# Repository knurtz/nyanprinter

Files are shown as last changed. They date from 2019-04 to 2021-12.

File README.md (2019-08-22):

# NyanPrinter
This printer runs on STM32F103 and it prints AND plays the nyan cat!

## Idea

Thermal printers make a lot of noise while printing -- everyone, who has bought something from a shop with one of those old cash registers knows that! At the heart of such a printer lies of course a stepper motor. Making music with stepper motors is an old thing in the Arduino community. But as far as I know, nobody has ever tried to make music AND print something at the same time -- until now!

Getting picture and sound to line up is not particulary easy, because there are certain limitations to the printing speed of a thermal printer -- and thus also for the maximum pitch we can get out of the machine. 

The datasheet recommends an approximate exposure of 1 ms per line, which responds to a 1 kHz pitch. This is, unless more than 64 pixels out of the total 384 pixels per line are printed simultanously. Here we need to do devided printing, which means multiple exposure bursts for one single line. This is where things get tricky. I need to let the printer run at a fixed speed and cannot stop at a line just because I want to print more than 64 pixels. Otherwise I would get a sudden break in my music.

This is the solution I came up with: If the printer encounters a line with more than 64 pixels, it prints the first 64 (or less) pixels, then advances the motor one step, going back one step immediately in order to print the next 64 pixels and so on. I have not yet tested, if the sudden change in direction is audible. If so, I might have to change it up a little bit and print multiple lines first, then go back over them a second time.

## Hardware

- STM32F103 Bluepill Development Board: [stm32duino.com](https://web.archive.org/web/20190524151648/https://wiki.stm32duino.com/index.php?title=Blue_Pill)
- Thermal printer MATSUSHITA EPL1801S2E from [pollin.de](https://www.pollin.de/p/thermo-druckelement-matsushita-epl1801s2e-721066)
- an awesome huge blue push button from [Amazon](https://www.amazon.de/gp/product/B07BSFMZJ2) (it lights up, too!)
- A4988 stepper motor driver board like this one from [pololu.com](https://www.pololu.com/product/1182)
- RECOM R-78E5.0-0.5 DC/DC converter from [conrad.de](https://www.conrad.de/de/recom-r-78e50-05-dcdc-wandler-print-24-vdc-5-vdc-500-ma-anzahl-ausgaenge-1-x-157954.html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)
- MAX6966 led driver from [farnell.com](https://de.farnell.com/maxim-integrated-products/max6966aee/led-treiber-mit-i-o-erweiterung/dp/2516036) for fancy led stuff
- custom milled PCB with some additional components like resistors and capacitors (Eagle files following shortly)
- custom enclosure printed with the amazing Vertigo Starlight filament from [filamentworld.de](https://www.filamentworld.de/shop/pla-filament-3d-drucker/pla-filament-1-75-mm-vertigo-starlight-075-kg/) (STL files following shortly as well)

## Software

I wanted to learn more about hardware peripherals of the STM32 family in this project. This is why I use a total of 3 timers, 2 DMA channels, one SPI and one UART peripheral. Things could have probably be done less complicated, but I would not have learned anything the easy way.

TIM2 is responsible for the motor step signal. It runs at a frequency that is determined by the current pitch of the music. The motor driver makes a step at every rising edge of the signal. Also, the printer needs to advance two steps for every line. Because of that, at every update interrupt of TIM2 (which corresponds to every step of the motor) I alternate between sending new data to the printer (triggering TIM1) and starting the exposure (triggering TIM3).

Data transfer is timed by TIM1, which triggers 64 DMA requests (64 transfers * 6 "pixels" per transfer = 384 pixels per line). The DMA sends the data to 6 parallel data lines that go into 6 shift registers inside the printer. Data alignment looks weird, this is why I wrote a small python script to convert images to a special byte array.

Finally TIM3 creates a pulse that corresponds to the needed exposure time of about 750 - 1000 us (depending on the supply voltage).

UART is needed for debugging and SPI for the led driver.

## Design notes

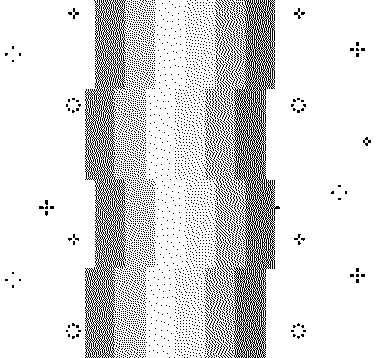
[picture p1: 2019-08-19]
Image/Source/nyan_indexed_loop.png

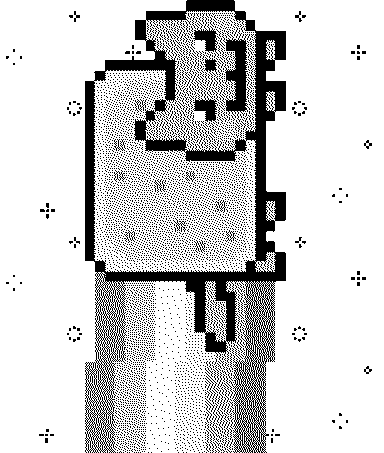
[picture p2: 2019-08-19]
Image/Source/nyan_indexed_start.png

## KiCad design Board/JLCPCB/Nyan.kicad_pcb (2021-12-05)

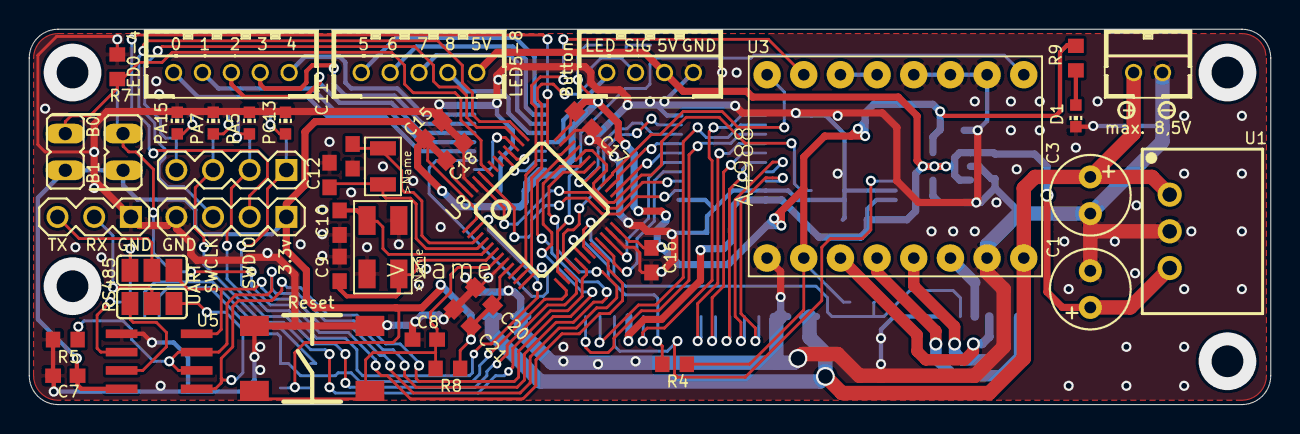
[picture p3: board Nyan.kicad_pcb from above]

Board: 2 copper layers, 86.0 x 26.0 mm, 66 parts (0 on the bottom side), 75 nets.

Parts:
C1, C3: 100u; E2,5-6
C2, C14, C21: 1u; C0603
C4, C5, C6, C7, C8, C15, C16, C17, C18, C20, C22: 100n; C0603
C9, C10: 30p; C0603
C11, C12: 15p; C0603
C13: 22n; C0603
C19: 10u; C0603
D1, D2, D3, D4, D5: CHIP-LED0603
JP1, JP2: JP1
Q1: 8M; SMD_5X3.2
Q2: 32768; SMD_3.2X1.5
R1: 300; R0603
R2: 47k; R0603
R3, R4, R5, R6, R7, R8, R9, R10, R11, R12, R13, R14: 10k; R0603
S1: 6X6_MOMENTARY_SWITCH
SJ1, SJ2: SJ_2
SV2, SV3: MA04-1_ROUND
U1: R-78C5.0-1.0; SIP3
U2: SOT23-5
U3: A4988_STEP
U4: MAX6966; QSOP-16
U5: ST3485; SO-08
U6, U7: 74HCT541PW; TSSOP20
U8: STM32F10XCXT6; TQFP48
X1: WR-WTB2.0-2_THT-VER; WR-WTB2.0-2-THT-VER
X2: WR-WTB2.0-4_THT_VER; WR-WTB2.0-4-THT-VER
X3, X4: WR-WTB2.0-5_THT-VER; WR-WTB2.0-5-THT-VER
X5: MA03-1_ROUND
X6: 68610614122
X7: 68612414422
X8: 68610414122

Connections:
+3V3: C4.1, C7.2, C14.1, C15.2, C16.2, C17.2, C18.2, C19.2, C20.2, C21.2, JP1.2, JP2.2, R1.2, R2.2, R3.2, R4.2, R8.2, R9.2, R14.1, SV2.1, U2.5, U3.VDD, U4.16, U5.8, U8.1, U8.9, U8.24, U8.36, U8.48
+5V: C1.+, C2.1, C5.2, C6.2, U1.3, U2.1, U2.3, U6.20, U7.20, X2.2, X4.1, X7.14
+12V: C3.+, U1.1, U3.VMOT, X1.2, X7.1, X7.2, X7.23, X7.24
A/TX: SJ1.2, X5.3
B/RX: SJ2.2, X5.2
BOOT0: JP1.1, R7.2, U8.44
BOOT1: JP2.1, R6.2, U8.20
BUT_LED: U4.13, X2.4
BUT_SIG: C22.1, R14.2, U8.11, X2.3
D1: U6.2, U8.45
D1_5V: U6.18, X7.5
D2: U6.3, U8.46
D2_5V: U6.17, X7.6
D3: U6.4, U8.21
D3_5V: U6.16, X7.7
D4: U6.5, U8.22
D4_5V: U6.15, X7.8
D5: U6.6, U8.25
D5_5V: U6.14, X7.9
D6: U6.7, U8.26
D6_5V: U6.13, X7.17
DCLK: U6.8, U8.29
DCLK_5V: U6.12, X7.16
FREE_LED: U4.12, X4.2
GND: C1.-, C2.2, C3.-, C4.2, C5.1, C6.1, C7.1, C8.1, C9.2, C10.2, C11.2, C12.2, C13.2, C14.2, C15.1, C16.1, C17.1, C18.1, C19.1, C20.1, C21.1, C22.2, D1.C, D2.C, D3.C, D4.C, D5.C, Q1.2, Q1.4, R5.1, R6.1, R7.1, S1.3, S1.4, SV2.4, U1.2, U2.2, U3.GND, U3.GND2, U3.MS1, U3.MS2, U3.MS3, U4.8, U5.5, U6.1, U6.10, U6.19, U7.1, U7.10, U7.19, U8.8, U8.23, U8.35, U8.47, X1.1, X2.1, X5.1, X6.6, X7.3, X7.4, X7.21, X7.22, X8.2
HEAD_THERM: R4.1, U8.18, X7.12
LATCH: U7.2, U8.28, U8.32
LATCH_5V: U7.18, X7.15
LED1: U4.3, X3.5
LED2: U4.4, X3.4
LED3: U4.5, X3.3
LED4: U4.6, X3.2
LED5: U4.7, X3.1
LED6: U4.9, X4.5
LED7: U4.10, X4.4
LED8: U4.11, X4.3
LED_CLK: U4.1, U8.39
LED_CS: U4.2, U8.12
LED_MISO: U4.14, U8.40
LED_MOSI: U4.15, U8.41
M1A: U3.1A, X6.1
M1B: U3.1B, X6.3
M2A: U3.2A, X6.2
M2B: U3.2B, X6.4
MOT_DIR: U3.DIR, U8.27
MOT_EN: U3./EN, U8.14
MOT_STP: U3.STEP, U8.10
MOT_THERM: R3.1, U8.19, X6.5
unnamed: R1.1, X8.4
unnamed: U3./RST, U3./SLP
unnamed: C8.2, R8.1, S1.1, S1.2, U8.7
unnamed: C12.1, Q2.1, U8.4
unnamed: C11.1, Q2.2, U8.3
unnamed: C10.1, Q1.3, U8.5
unnamed: C9.1, Q1.1, U8.6
unnamed: D4.A, R12.1
unnamed: D1.A, R9.1
unnamed: D2.A, R10.1
unnamed: D3.A, R11.1
unnamed: C13.1, U2.4
unnamed: D5.A, R13.1
PA5: R11.2, SV3.2, U8.15
PA7: R12.2, SV3.3, U8.17
PA15: R13.2, SV3.4, U8.38
PC13: R10.2, SV3.1, U8.2
PHOTO: R2.1, U8.13, X8.3
RS485_A: SJ1.3, U5.6
RS485_B: SJ2.1, U5.7
RTS: R5.2, U5.2, U5.3, U8.33
RX: SJ2.3, U5.1, U8.31
STROBE: U6.9, U8.16
STROBE_5V: U6.11, X7.13
SWCLK: SV2.3, U8.37
SWDIO: SV2.2, U8.34
TX: SJ1.1, U5.4, U8.30

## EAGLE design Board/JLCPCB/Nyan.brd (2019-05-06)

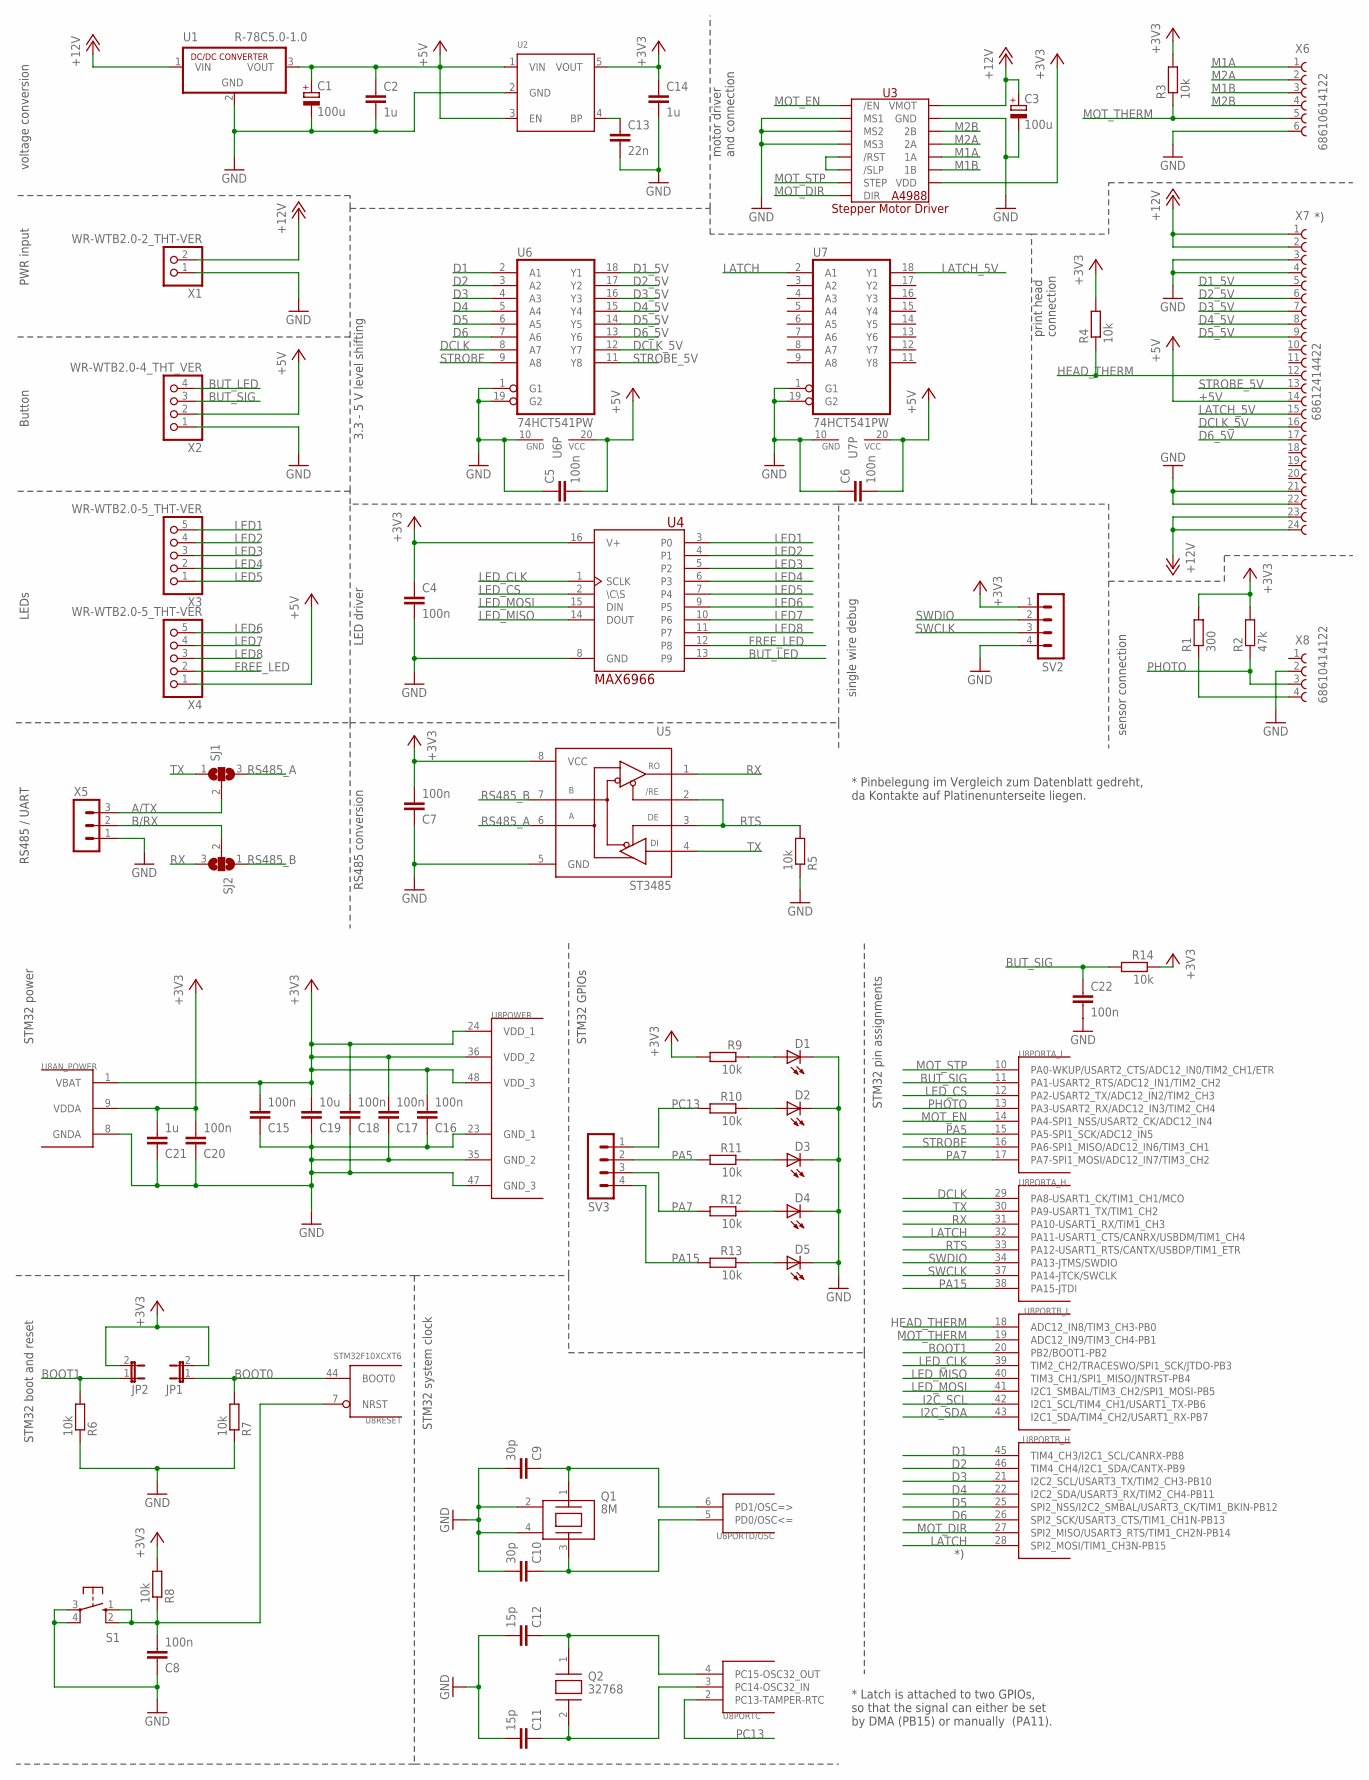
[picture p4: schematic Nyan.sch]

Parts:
C1, C3: 100u; E2,5-6
C2, C14, C21: 1u; C0603
C4, C5, C6, C7, C8, C15, C16, C17, C18, C20, C22: 100n; C0603
C9, C10: 30p; C0603
C11, C12: 15p; C0603
C13: 22n; C0603
C19: 10u; C0603
D1, D2, D3, D4, D5: LEDCHIP-LED0603; CHIP-LED0603
JP1, JP2: JP1E; JP1
Q1: 8M; SMD_5X3.2
Q2: 32768; SMD_3.2X1.5
R1: 300; R0603
R2: 47k; R0603
R3, R4, R5, R6, R7, R8, R9, R10, R11, R12, R13, R14: 10k; R0603
S1: 6X6_MOMENTARY_SWITCH
SJ1, SJ2: SJ2W; SJ_2
SV2, SV3: MA04-1ROUND_PAD; MA04-1_ROUND
U1: R-78C5.0-1.0; SIP3
U2: RT9193; SOT23-5
U3: A4988_STEP
U4: MAX6966; QSOP-16
U5: ST3485; SO-08
U6, U7: 74HCT541PW; TSSOP20
U8: STM32F10XCXT6; TQFP48
X1: WR-WTB2.0-2_THT-VER; WR-WTB2.0-2-THT-VER
X2: WR-WTB2.0-4_THT_VER; WR-WTB2.0-4-THT-VER
X3, X4: WR-WTB2.0-5_THT-VER; WR-WTB2.0-5-THT-VER
X5: MA03-1ROUND_PAD; MA03-1_ROUND
X6: 68610614122
X7: 68612414422
X8: 68610414122

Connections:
+3V3: C4.1, C7.2, C14.1, C15.2, C16.2, C17.2, C18.2, C19.2, C20.2, C21.2, JP1.2, JP2.2, R1.2, R2.2, R3.2, R4.2, R8.2, R9.2, R14.1, SV2.1, U2.5 (VOUT), U3.VDD, U4.16 (V+), U5.8 (VCC), U8.1 (VBAT), U8.9 (VDDA), U8.24 (VDD_1), U8.36 (VDD_2), U8.48 (VDD_3)
+5V: C1.+, C2.1, C5.2, C6.2, U1.3 (VOUT), U2.1 (VIN), U2.3 (EN), U6.20 (VCC), U7.20 (VCC), X2.2, X4.1, X7.14
+12V: C3.+, U1.1 (VIN), U3.VMOT, X1.2, X7.1, X7.2, X7.23, X7.24
A/TX: SJ1.2, X5.3
B/RX: SJ2.2, X5.2
BOOT0: JP1.1, R7.2, U8.44 (BOOT0)
BOOT1: JP2.1, R6.2, U8.20 (PB2/BOOT1-PB2)
BUT_LED: U4.13 (P9), X2.4
BUT_SIG: C22.1, R14.2, U8.11 (PA1-USART2_RTS/ADC12_IN1/TIM2_CH2), X2.3
D1: U6.2 (A1), U8.45 (TIM4_CH3/I2C1_SCL/CANRX-PB8)
D1_5V: U6.18 (Y1), X7.5
D2: U6.3 (A2), U8.46 (TIM4_CH4/I2C1_SDA/CANTX-PB9)
D2_5V: U6.17 (Y2), X7.6
D3: U6.4 (A3), U8.21 (I2C2_SCL/USART3_TX/TIM2_CH3-PB10)
D3_5V: U6.16 (Y3), X7.7
D4: U6.5 (A4), U8.22 (I2C2_SDA/USART3_RX/TIM2_CH4-PB11)
D4_5V: U6.15 (Y4), X7.8
D5: U6.6 (A5), U8.25 (SPI2_NSS/I2C2_SMBAL/USART3_CK/TIM1_BKIN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)
D5_5V: U6.14 (Y5), X7.9
D6: U6.7 (A6), U8.26 (SPI2_SCK/USART3_CTS/TIM1_CH1N-PB13)
D6_5V: U6.13 (Y6), X7.17
DCLK: U6.8 (A7), U8.29 (PA8-USART1_CK/TIM1_CH1/MCO)
DCLK_5V: U6.12 (Y7), X7.16
FREE_LED: U4.12 (P8), X4.2
GND: C1.-, C2.2, C3.-, C4.2, C5.1, C6.1, C7.1, C8.1, C9.2, C10.2, C11.2, C12.2, C13.2, C14.2, C15.1, C16.1, C17.1, C18.1, C19.1, C20.1, C21.1, C22.2, D1.C, D2.C, D3.C, D4.C, D5.C, Q1.2, Q1.4, R5.1, R6.1, R7.1, S1.3, S1.4, SV2.4, U1.2 (GND), U2.2 (GND), U3.GND, U3.GND2 (GND), U3.MS1, U3.MS2, U3.MS3, U4.8 (GND), U5.5 (GND), U6.1 (G1), U6.10 (GND), U6.19 (G2), U7.1 (G1), U7.10 (GND), U7.19 (G2), U8.8 (GNDA), U8.23 (GND_1), U8.35 (GND_2), U8.47 (GND_3), X1.1, X2.1, X5.1, X6.6, X7.3, X7.4, X7.21, X7.22, X8.2
HEAD_THERM: R4.1, U8.18 (ADC12_IN8/TIM3_CH3-PB0), X7.12
I2C_SCL: U8.42 (I2C1_SCL/TIM4_CH1/USART1_TX-PB6)
I2C_SDA: U8.43 (I2C1_SDA/TIM4_CH2/USART1_RX-PB7)
LATCH: U7.2 (A1), U8.28 (SPI2_MOSI/TIM1_CH3N-PB15), U8.32 (PA11-USART1_CTS/CANRX/USBDM/TIM1_CH4)
LATCH_5V: U7.18 (Y1), X7.15
LED1: U4.3 (P0), X3.5
LED2: U4.4 (P1), X3.4
LED3: U4.5 (P2), X3.3
LED4: U4.6 (P3), X3.2
LED5: U4.7 (P4), X3.1
LED6: U4.9 (P5), X4.5
LED7: U4.10 (P6), X4.4
LED8: U4.11 (P7), X4.3
LED_CLK: U4.1 (SCLK), U8.39 (TIM2_CH2/TRACESWO/SPI1_SCK/JTDO-PB3)
LED_CS: U4.2 (\C\S), U8.12 (PA2-USART2_TX/ADC12_IN2/TIM2_CH3)
LED_MISO: U4.14 (DOUT), U8.40 (TIM3_CH1/SPI1_MISO/JNTRST-PB4)
LED_MOSI: U4.15 (DIN), U8.41 (I2C1_SMBAL/TIM3_CH2/SPI1_MOSI-PB5)
M1A: U3.1A, X6.1
M1B: U3.1B, X6.3
M2A: U3.2A, X6.2
M2B: U3.2B, X6.4
MOT_DIR: U3.DIR, U8.27 (SPI2_MISO/USART3_RTS/TIM1_CH2N-PB14)
MOT_EN: U3./EN, U8.14 (PA4-SPI1_NSS/USART2_CK/ADC12_IN4)
MOT_STP: U3.STEP, U8.10 (PA0-WKUP/USART2_CTS/ADC12_IN0/TIM2_CH1/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)
MOT_THERM: R3.1, U8.19 (ADC12_IN9/TIM3_CH4-PB1), X6.5
unnamed: R1.1, X8.4
unnamed: U3./RST, U3./SLP
unnamed: C8.2, R8.1, S1.1, S1.2, U8.7 (NRST)
unnamed: C12.1, Q2.1, U8.4 (PC15-OSC32_OUT)
unnamed: C11.1, Q2.2, U8.3 (PC14-OSC32_IN)
unnamed: C10.1, Q1.3, U8.5 (PD0/OSC<=)
unnamed: C9.1, Q1.1, U8.6 (PD1/OSC=>)
unnamed: D4.A, R12.1
unnamed: D1.A, R9.1
unnamed: D2.A, R10.1
unnamed: D3.A, R11.1
unnamed: C13.1, U2.4 (BP)
unnamed: D5.A, R13.1
PA5: R11.2, SV3.2, U8.15 (PA5-SPI1_SCK/ADC12_IN5)
PA7: R12.2, SV3.3, U8.17 (PA7-SPI1_MOSI/ADC12_IN7/TIM3_CH2)
PA15: R13.2, SV3.4, U8.38 (PA15-JTDI)
PC13: R10.2, SV3.1, U8.2 (PC13-TAMPER-RTC)
PHOTO: R2.1, U8.13 (PA3-USART2_RX/ADC12_IN3/TIM2_CH4), X8.3
RS485_A: SJ1.3, U5.6 (A)
RS485_B: SJ2.1, U5.7 (B)
RTS: R5.2, U5.2 (!RE), U5.3 (DE), U8.33 (PA12-USART1_RTS/CANTX/USBDP/TIM1_ETR)
RX: SJ2.3, U5.1 (RO), U8.31 (PA10-USART1_RX/TIM1_CH3)
STROBE: U6.9 (A8), U8.16 (PA6-SPI1_MISO/ADC12_IN6/TIM3_CH1)
STROBE_5V: U6.11 (Y8), X7.13
SWCLK: SV2.3, U8.37 (PA14-JTCK/SWCLK)
SWDIO: SV2.2, U8.34 (PA13-JTMS/SWDIO)
TX: SJ1.1, U5.4 (DI), U8.30 (PA9-USART1_TX/TIM1_CH2)

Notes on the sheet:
Button
PWR input
LEDs
RS485 / UART
* Latch is attached to two GPIOs, so that the signal can either be set by DMA (PB15) or manually (PA11).
* Pinbelegung im Vergleich zum Datenblatt gedreht, da Kontakte auf Platinenunterseite liegen.
voltage conversion
LED driver
RS485 conversion
3.3 - 5 V level shifting
motor driver and connection
print head connection
sensor connection
single wire debug
STM32 power
STM32 boot and reset
STM32 system clock
STM32 GPIOs
STM32 pin assignments

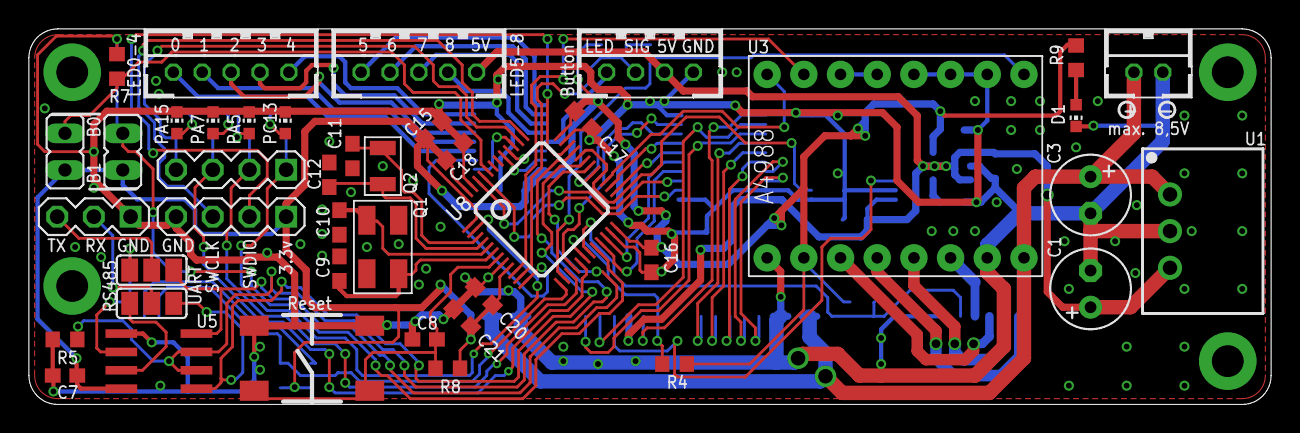
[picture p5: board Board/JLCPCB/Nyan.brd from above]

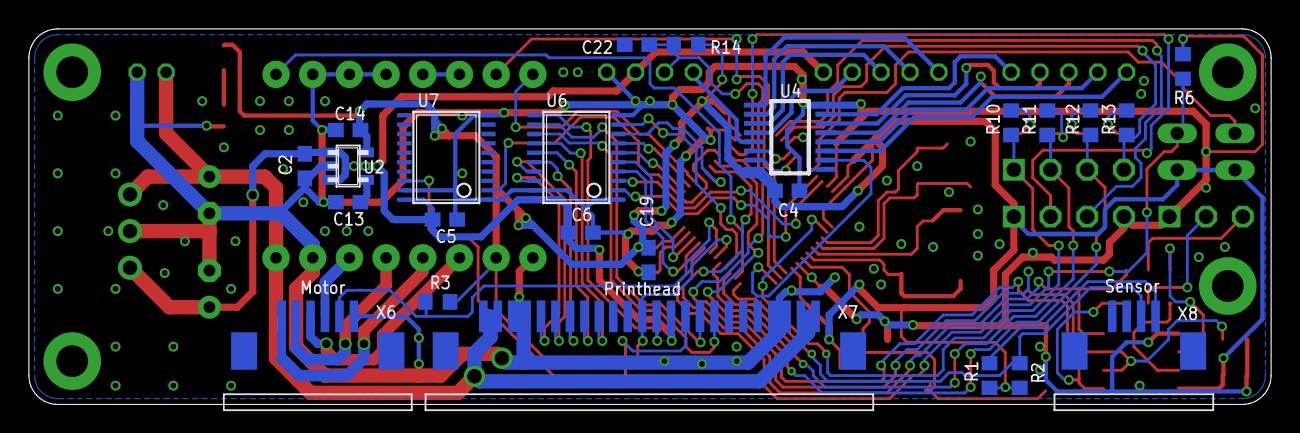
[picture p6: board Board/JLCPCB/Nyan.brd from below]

Board: 2 copper layers, 86.0 x 26.0 mm, 66 parts (24 on the bottom side), 75 nets.

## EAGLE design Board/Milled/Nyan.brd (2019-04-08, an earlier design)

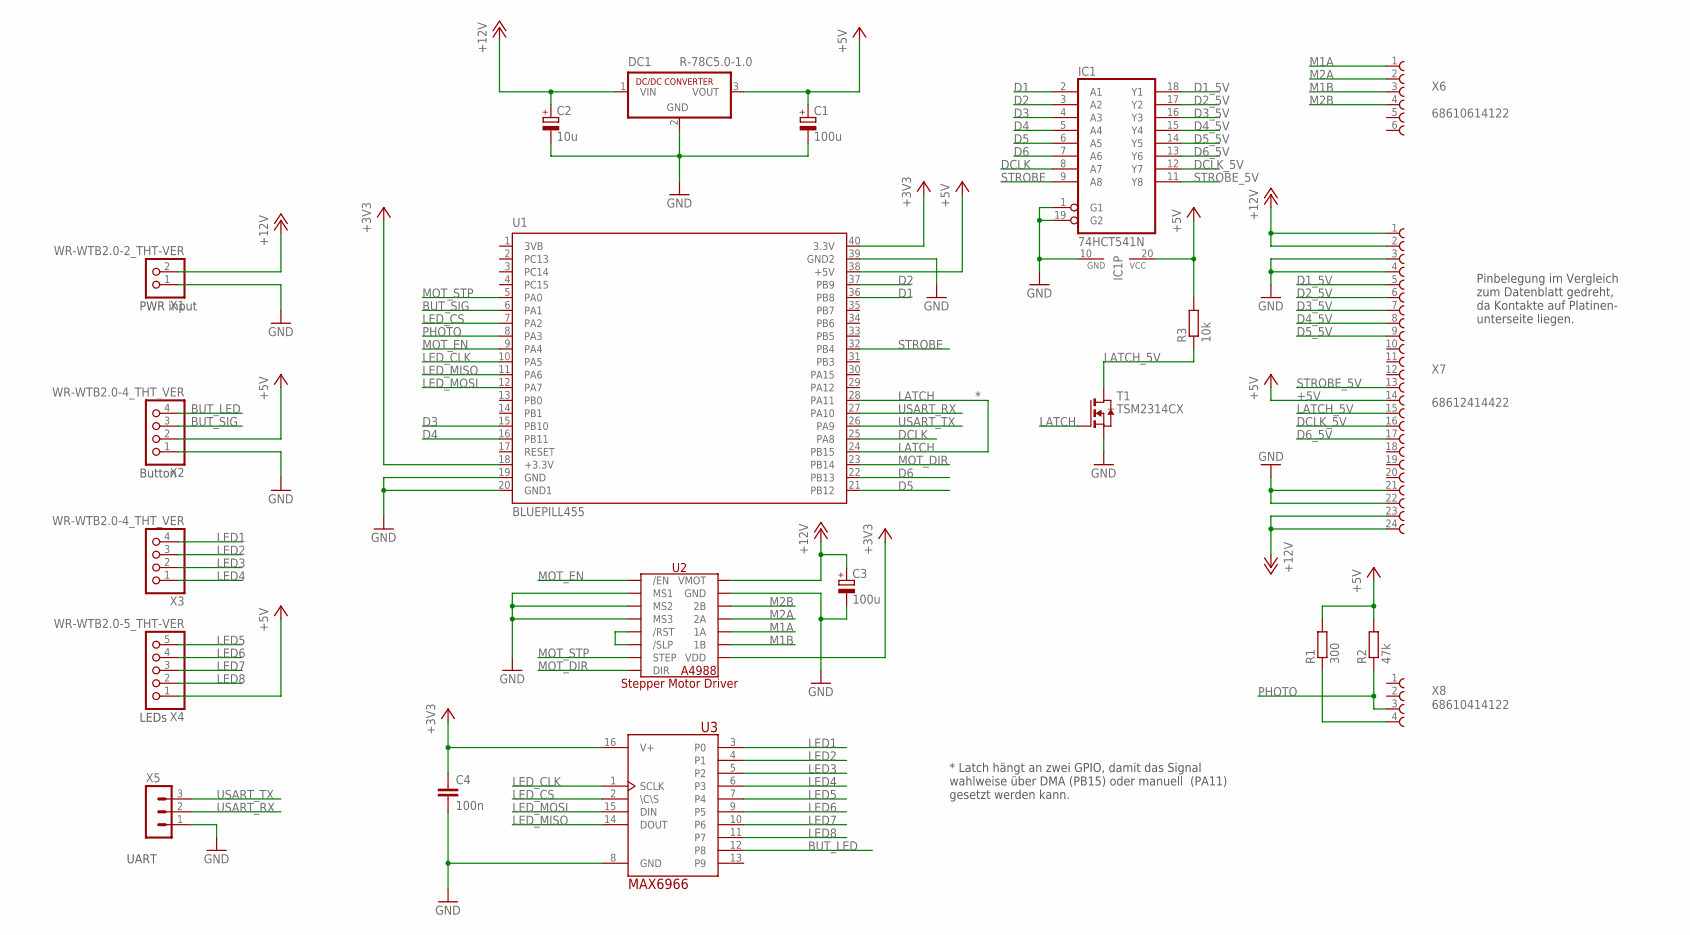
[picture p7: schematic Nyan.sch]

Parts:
C1, C3: 100u; E2,5-6
C2: 10u; E2,5-6
C4: 100n; C075-032X103
DC1: R-78C5.0-1.0; SIP3
IC1: 74HCT541N; DIL20
R1: 300; 0204/7
R2: 47k; 0204/7
R3: 10k; R0603
T1: TSM2314CX; SOT-23
U1: BLUEPILL455; DIL40
U2: A4988_STEP
U3: MAX6966; QSOP-16
X1: WR-WTB2.0-2_THT-VER; WR-WTB2.0-2-THT-VER
X2, X3: WR-WTB2.0-4_THT_VER; WR-WTB2.0-4-THT-VER
X4: WR-WTB2.0-5_THT-VER; WR-WTB2.0-5-THT-VER
X5: MA03-1ROUND_PAD; MA03-1_ROUND
X6: 68610614122
X7: 68612414422
X8: 68610414122

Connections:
+3V3: C4.1, U1.18 (+3.3V), U1.40 (3.3V), U2.VDD, U3.16 (V+)
+5V: C1.+, DC1.3 (VOUT), IC1.20 (VCC), R1.2, R2.2, R3.2, U1.38 (+5V), X2.2, X4.1, X7.14
+12V: C2.+, C3.+, DC1.1 (VIN), U2.VMOT, X1.2, X7.1, X7.2, X7.23, X7.24
BUT_LED: U3.12 (P8), X2.4
BUT_SIG: U1.6 (PA1), X2.3
D1: IC1.2 (A1), U1.36 (PB8)
D1_5V: IC1.18 (Y1), X7.5
D2: IC1.3 (A2), U1.37 (PB9)
D2_5V: IC1.17 (Y2), X7.6
D3: IC1.4 (A3), U1.15 (PB10)
D3_5V: IC1.16 (Y3), X7.7
D4: IC1.5 (A4), U1.16 (PB11)
D4_5V: IC1.15 (Y4), X7.8
D5: IC1.6 (A5), U1.21 (PB12)
D5_5V: IC1.14 (Y5), X7.9
D6: IC1.7 (A6), U1.22 (PB13)
D6_5V: IC1.13 (Y6), X7.17
DCLK: IC1.8 (A7), U1.25 (PA8)
DCLK_5V: IC1.12 (Y7), X7.16
GND: C1.-, C2.-, C3.-, C4.2, DC1.2 (GND), IC1.1 (G1), IC1.10 (GND), IC1.19 (G2), T1.2 (S), U1.19 (GND), U1.20 (GND1), U1.39 (GND2), U2.GND, U2.GND2 (GND), U2.MS1, U2.MS2, U2.MS3, U3.8 (GND), X1.1, X2.1, X5.1, X7.3, X7.4, X7.21, X7.22
LATCH: T1.1 (G), U1.24 (PB15), U1.28 (PA11)
LATCH_5V: R3.1, T1.3 (D), X7.15
LED1: U3.3 (P0), X3.4
LED2: U3.4 (P1), X3.3
LED3: U3.5 (P2), X3.2
LED4: U3.6 (P3), X3.1
LED5: U3.7 (P4), X4.5
LED6: U3.9 (P5), X4.4
LED7: U3.10 (P6), X4.3
LED8: U3.11 (P7), X4.2
LED_CLK: U1.10 (PA5), U3.1 (SCLK)
LED_CS: U1.7 (PA2), U3.2 (\C\S)
LED_MISO: U1.11 (PA6), U3.14 (DOUT)
LED_MOSI: U1.12 (PA7), U3.15 (DIN)
M1A: U2.1A, X6.1
M1B: U2.1B, X6.3
M2A: U2.2A, X6.2
M2B: U2.2B, X6.4
MOT_DIR: U1.23 (PB14), U2.DIR
MOT_EN: U1.9 (PA4), U2./EN
MOT_STP: U1.5 (PA0), U2.STEP
unnamed: R1.1, X8.4
unnamed: U2./RST, U2./SLP
PB3: U1.31 (PB3)
PHOTO: R2.1, U1.8 (PA3), X8.3
STROBE: IC1.9 (A8), U1.32 (PB4)
STROBE_5V: IC1.11 (Y8), X7.13
USART_RX: U1.27 (PA10), X5.2
USART_TX: U1.26 (PA9), X5.3

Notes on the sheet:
Button
PWR input
LEDs
UART
* Latch hängt an zwei GPIO, damit das Signal wahlweise über DMA (PB15) oder manuell (PA11) gesetzt werden kann.
Pinbelegung im Vergleich zum Datenblatt gedreht, da Kontakte auf Platinen- unterseite liegen.

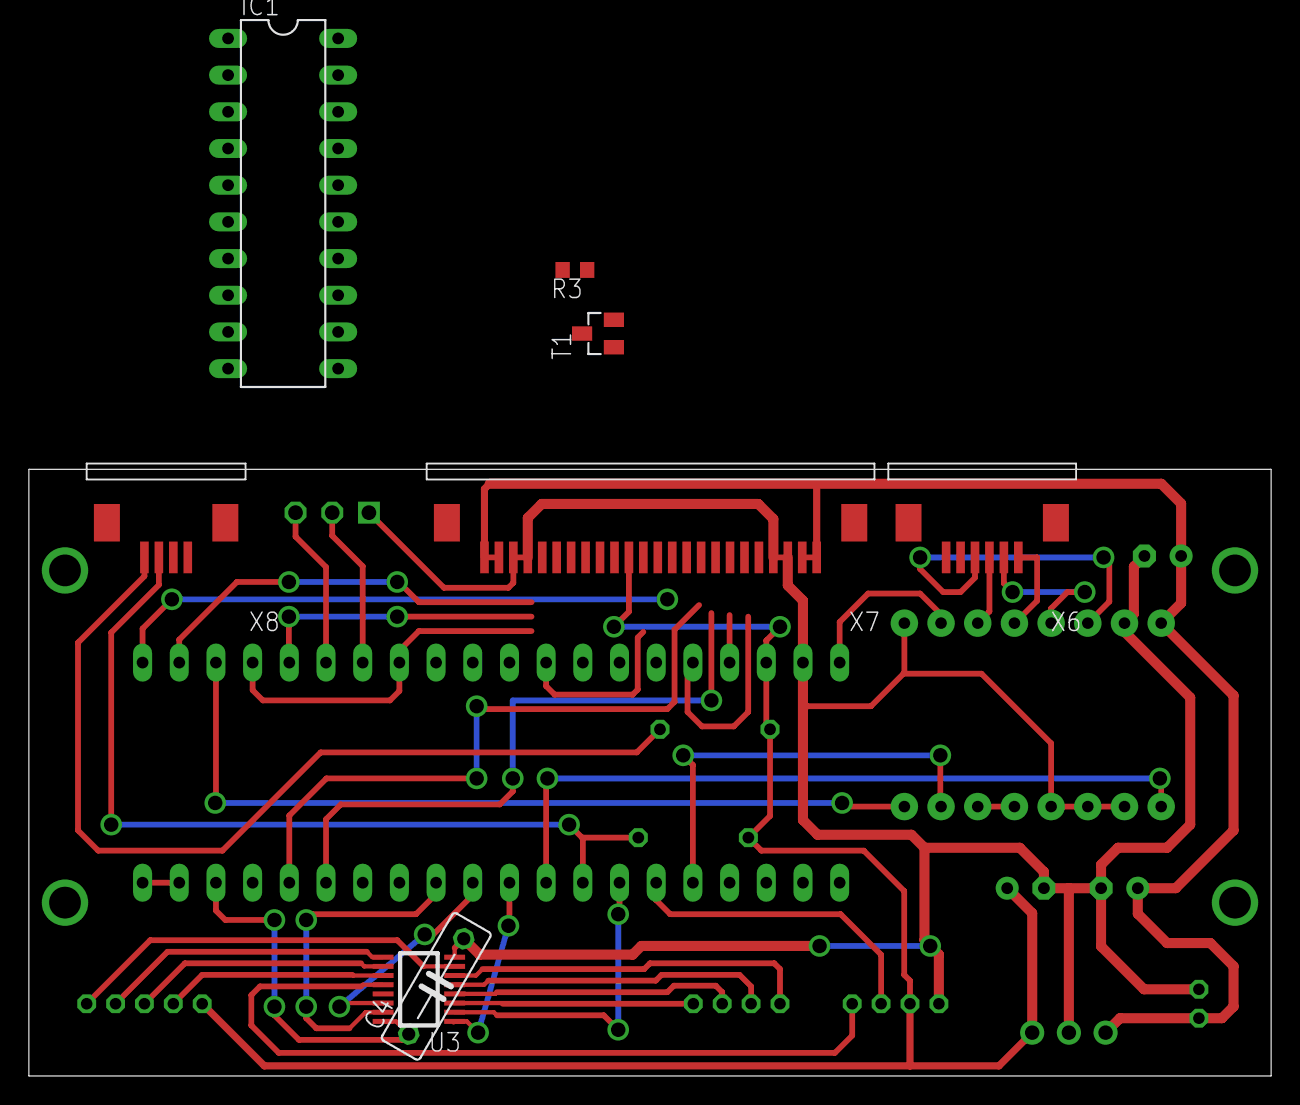
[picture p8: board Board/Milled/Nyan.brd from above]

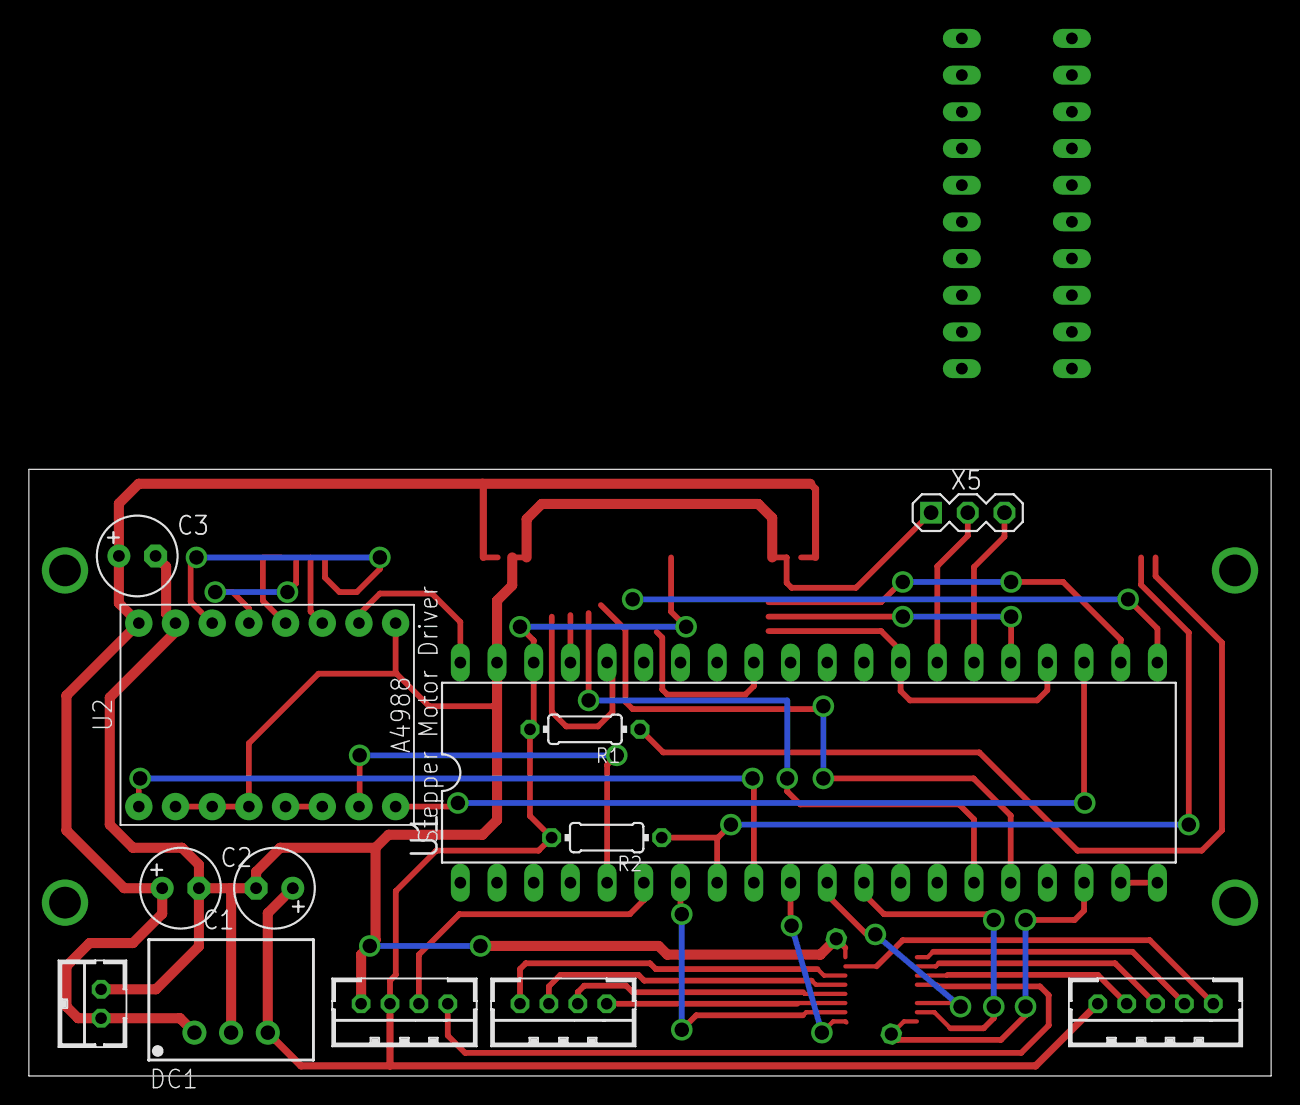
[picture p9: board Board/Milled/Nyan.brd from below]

Board: 2 copper layers, 86.0 x 42.0 mm, 21 parts (13 on the bottom side), 48 nets.

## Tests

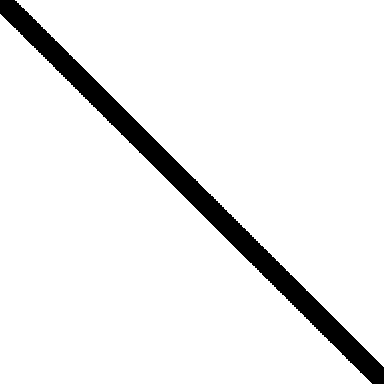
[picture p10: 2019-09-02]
Image/Source/test.png

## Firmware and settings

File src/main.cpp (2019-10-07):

/**
 * @main.cpp
 *
 * NyanPrinter main source code
 *
 * Johannes Herold, 2019
 *
 * Additional info on STM32F103
 * https://www.st.com/en/microcontrollers/stm32f103.html?querycriteria=productId=LN1565
 *
 */

#include "stm32f10x.h"
#include "stm32f10x_conf.h"

#include "delay.h"
#include "init.h"
#include "helper.h"
#include "pins.h"
#include "notes.h"

#include "image_nyan_start.h"
#include "image_nyan_loop.h"

#define FRAMERATE				25
#define FRAME_PERIOD			400
#define BREATHING_PERIOD		4

#define MUSIC_BPM				120
const int thirtysecond = (60000 / MUSIC_BPM) >> 5;		// amount of milliseconds for one thirtysecond note

int frametimer = 0;				// duration until next frame update
int musictimer = 0;				// duration until next note

uint8_t current_frame = 0;

uint8_t breathing_table[] = {
	3, 3, 3, 3, 4, 4, 5, 6, 8, 9, 11, 13, 15, 17, 20,
	23, 26, 29, 33, 37, 42, 46, 52, 57, 64, 70, 77, 84,
	92, 100, 109, 118, 127, 136, 146, 155, 165, 175, 185,
	194, 203, 212, 220, 227, 234, 240, 245, 248, 251, 253,
	254, 253, 251, 248, 245, 240, 234, 227, 220, 212, 203,
	194, 185, 175, 165, 155, 146, 136, 127, 118, 109, 100,
	92, 84, 77, 70, 64, 57, 52, 46, 42, 37, 33, 29, 26, 23,
	20, 17, 15, 13, 11, 9, 8, 6, 5, 4, 4, 3, 3, 3
};


int main(void) {

	SystemInit();


	// initialize some stuff
	delay_init(DELAY_RESOLUTION_100_US);				// configures systick and systick handler, resets uptime counter
	gpio_init();
	printer_clk_init();
	motor_step_init();
	printer_strobe_init();
	image_dma_init(image_nyan_start, image_nyan_start_length);
	led_spi_init();

	// enable motor
	GPIO_WriteBit(MOTOR_EN_PORT, MOTOR_EN_PIN, MOTOR_EN_SET_STATE);
	//set_motor_freq(NOTE_D);
	TIM_Cmd(TIM2, ENABLE);

	while(1) {

		// wait until another interval of delay resolution has passed
		while(!systick_int);
		systick_int = 0;

		// if (musictimer >= music_interval)
		// get next note / pause from song array
		// set pitch or disable motor for a pause
		// calculate new value for musictimer
		// musictimer = thirtysecond << 2		// example for one sixteenth length

		if (!frametimer) {
			frametimer = FRAME_PERIOD;
			spi_led_send(4, breathing_table[current_frame++]);			// update debug led attached to P4
			if (current_frame >= (FRAMERATE * BREATHING_PERIOD)) current_frame = 0;
		}

		musictimer--;
		frametimer--;			// systick configured to 1000 Hz -> counts milliseconds

	}

	return 0;
}

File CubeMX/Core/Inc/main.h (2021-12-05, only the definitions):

#define false   0
#define true    1
#define LED1_Pin GPIO_PIN_13
#define LED1_GPIO_Port GPIOC
#define MOT_STP_Pin GPIO_PIN_0
#define MOT_STP_GPIO_Port GPIOA
#define BIG_BUTTON_Pin GPIO_PIN_1
#define BIG_BUTTON_GPIO_Port GPIOA
#define LED_CS_Pin GPIO_PIN_2
#define LED_CS_GPIO_Port GPIOA
#define PHOTO_Pin GPIO_PIN_3
#define PHOTO_GPIO_Port GPIOA
#define MOT_EN_Pin GPIO_PIN_4
#define MOT_EN_GPIO_Port GPIOA
#define LED2_Pin GPIO_PIN_5
#define LED2_GPIO_Port GPIOA
#define STROBE_Pin GPIO_PIN_6
#define STROBE_GPIO_Port GPIOA
#define LED3_Pin GPIO_PIN_7
#define LED3_GPIO_Port GPIOA
#define HEAD_NTC_Pin GPIO_PIN_0
#define HEAD_NTC_GPIO_Port GPIOB
#define MOT_NTC_Pin GPIO_PIN_1
#define MOT_NTC_GPIO_Port GPIOB
#define D3_Pin GPIO_PIN_10
#define D3_GPIO_Port GPIOB
#define D4_Pin GPIO_PIN_11
#define D4_GPIO_Port GPIOB
#define D5_Pin GPIO_PIN_12
#define D5_GPIO_Port GPIOB
#define D6_Pin GPIO_PIN_13
#define D6_GPIO_Port GPIOB
#define MOT_DIR_Pin GPIO_PIN_14
#define MOT_DIR_GPIO_Port GPIOB
#define DCLK_Pin GPIO_PIN_8
#define DCLK_GPIO_Port GPIOA
#define LATCH_Pin GPIO_PIN_11
#define LATCH_GPIO_Port GPIOA
#define LED4_Pin GPIO_PIN_15
#define LED4_GPIO_Port GPIOA
#define LED_CLK_Pin GPIO_PIN_3
#define LED_CLK_GPIO_Port GPIOB
#define LED_MISO_Pin GPIO_PIN_4
#define LED_MISO_GPIO_Port GPIOB
#define LED_MOSI_Pin GPIO_PIN_5
#define LED_MOSI_GPIO_Port GPIOB
#define D1_Pin GPIO_PIN_8
#define D1_GPIO_Port GPIOB
#define D2_Pin GPIO_PIN_9
#define D2_GPIO_Port GPIOB

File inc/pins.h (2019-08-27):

/*
 * pins.h
 *
 *  Created on: May 27, 2019
 *  Author: Johannes Herold
 */

#ifndef PINS_H_
#define PINS_H_


// ******** Onboard LED pins ***********
#define LED1_PORT                   GPIOA
#define LED1_PIN                    GPIO_Pin_15

#define LED2_PORT                   GPIOA
#define LED2_PIN                    GPIO_Pin_7

#define LED3_PORT                   GPIOA
#define LED3_PIN                    GPIO_Pin_5

#define LED4_PORT                   GPIOC
#define LED4_PIN                    GPIO_Pin_13

#define LED_SET_STATE				Bit_SET
#define LED_RESET_STATE				Bit_RESET


// ******** SPI LED driver pins ***********
#define LED_CS_PORT	 				GPIOA
#define LED_CS_PIN					GPIO_Pin_2
#define LED_CS_SET_STATE			Bit_RESET
#define LED_CS_RESET_STATE			Bit_SET

#define LED_CLOCK_PORT				GPIOB
#define LED_CLOCK_PIN				GPIO_Pin_3

#define LED_MISO_PORT				GPIOB
#define LED_MISO_PIN				GPIO_Pin_4

#define LED_MOSI_PORT				GPIOB
#define LED_MOSI_PIN				GPIO_Pin_5


// ******** MOTOR pins ***********
#define MOTOR_STEP_PORT             GPIOA
#define MOTOR_STEP_PIN              GPIO_Pin_0

#define MOTOR_EN_PORT               GPIOA
#define MOTOR_EN_PIN                GPIO_Pin_4
#define MOTOR_EN_SET_STATE			Bit_RESET
#define MOTOR_EN_RESET_STATE		Bit_SET

#define MOTOR_DIR_PORT				GPIOB
#define MOTOR_DIR_PIN				GPIO_Pin_14
#define MOTOR_DIR_FORWARD			Bit_SET
#define	MOTOR_DIR_BACKWARD			Bit_RESET


// ******** PRINTER pins ***********
#define PRINTER_STROBE_PORT         GPIOA
#define PRINTER_STROBE_PIN          GPIO_Pin_6

#define PRINTER_CLK_PORT            GPIOA
#define PRINTER_CLK_PIN             GPIO_Pin_8

#define PRINTER_LATCH_PORT          GPIOA
#define PRINTER_LATCH_PIN           GPIO_Pin_11
#define PRINTER_LATCH_SET_STATE		Bit_RESET
#define PRINTER_LATCH_RESET_STATE	Bit_SET

#define PRINTER_DATA_PORT           GPIOB
#define PRINTER_DATA_PINS           GPIO_Pin_8 | GPIO_Pin_9 | GPIO_Pin_10 | GPIO_Pin_11 | GPIO_Pin_12 | GPIO_Pin_13 | GPIO_Pin_14


// ******** BUTTON pin ***********
#define BUTTON_PORT                 GPIOA
#define BUTTON_PIN                  GPIO_Pin_1


#endif /* PINS_H_ */

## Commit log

2019-03-30 Code for initialising the timers done, basic picture format as 2d array set up
2019-04-01 Timer und DMA konfiguriert
2019-04-01 Datenblatt und Planungsdateien
2019-04-01 minor changed that didn't help te problem
    [main.cpp]
2019-04-04 Motor dreht jetzt mit Timer PWM über CC1
2019-04-05 DMA transfer to GPIO works
2019-04-05 Python image analyzer copied from old Arduino project and modified for STM32 implementation
2019-04-05 Added printer name in readme
2019-04-05 Added image to code, test routine should work, doesn't :(
    [main.cpp]
2019-04-05 Fixed something, but still not working. Probably because of voltage differences between STM and printer :(
    [main.cpp]
2019-04-06 Eagle files for milled circuit board
    [Nyan.brd, Nyan.sch]
2019-04-08 Current development state with hardware fixes for 3 to 5 volt level shifting
    [Nyan.brd, Nyan.sch]
2019-04-11 Fixed PB4 being always high by disabling JTAG
    [main.cpp]
2019-04-11 Everything in interrupt routine, no manual triggering anymore
2019-04-14 [Board] Copied board for manufacturing at JLCPCB. Big changes
    [Nyan.brd, Nyan.sch]
2019-04-14 [Doku] Updated roadmap for new board (also english now)
2019-04-14 Added bluepill schematic as reference and STM32CubeMX Config files
2019-04-14 [Board] A little more layouting done
    [Nyan.brd, Nyan.sch]
2019-04-22 [Board] Positioning done
    [Nyan.brd]
2019-04-27 [Board] Fixed positions for half the components
    [Nyan.brd]
2019-04-27 [Board] Fixed positioning done
    [Nyan.brd]
2019-04-27 [Board] Some progress in routing
    [Nyan.brd, Nyan.sch]
2019-04-27 [Board] Some more traces :)
    [Nyan.brd]
2019-04-27 [Board] And even more traces
    [Nyan.brd]
2019-04-28 [Board] More layouting done
    [Nyan.brd, Nyan.sch]
2019-04-30 [Board] Layouting of first half (microcontroller side) done.
    [Nyan.brd]
2019-05-01 [Board] More layouting
    [Nyan.brd, Nyan.sch]
2019-05-03 [Board] almost complete, last gnd and 3v traces missing
    [Nyan.brd]
2019-05-03 [Board] Layout done
    [Nyan.brd]
2019-05-04 [Board] Silk Screen Top done
    [Nyan.brd, Nyan.sch]
2019-05-04 [Board] Silk Screen Bottom done
    [Nyan.brd]
2019-05-05 [Board] Silkscreen done, DRC checked
    [Nyan.brd, Nyan.sch]
2019-05-05 [Board] Fixed connection for crystals
    [Nyan.brd, Nyan.sch]
2019-05-06 [Board] Added debouncing circuitry for pushbutton
    [Nyan.brd, Nyan.sch]
2019-05-06 [Board] Finished for manufacturing
    [Nyan.brd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]
2019-05-28 Fixed misfiring interrupt. Test image works.
    [init.c, interrupt_routines.c]
2019-06-04 Added function for pitch adjustment
2019-06-10 Corrected intentation for all files
    [delay.h, helper.c, init.c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]
2019-08-20 [Tone generation] Added preload feature for step timer, possibly fixing interrupted notes
    [init.c, main.cpp]
2019-08-22 [SPI LED] Added defines and GPIO setup for SPI LED driver
2019-08-22 [STM32 Cube Config] Migrated to newer program version
2019-08-22 [SPI LED] Implemented initialization for SPI LED driver
2019-08-22 [Code] Added systick counter and interrupt to delay feature
2019-08-22 [Readme] Changed link to stm32duino.com to archive
2019-08-22 [Code] Changed default motor direction
2019-08-22 [Code] Modified breathing pattern to accomodate minimum and maximum values of MAX6966 LED driver
2019-08-27 [Code] Fixed misspelled variable name
    [delay.h, main.cpp]
2019-08-27 [SPI LED] Breathing LED in main loop works
2019-08-27 [SPI LED] Changed breathing period to 4 seconds
2019-08-27 [SPI LED] 20 mA current for LEDs
2019-08-31 [Code] Frame counter also counts down to avoid confusion
    [main.cpp]
2019-08-31 [Code] Latch fixed active
    [init.c, interrupt_routines.c, main.cpp]
2019-09-02 [Code] Static offset to iamge buffer fixes misaligned line
    [init.c]
2019-09-02 [Code] Back to nyan cat, 1/10th speed, finally a correct cat
    [init.c, main.cpp]
2021-12-05 Added KiCAD for Bom
    [Nyan.kicad_pcb]
2021-12-19 Added timer for strobe
2021-12-19 Added photoshop file for printed image

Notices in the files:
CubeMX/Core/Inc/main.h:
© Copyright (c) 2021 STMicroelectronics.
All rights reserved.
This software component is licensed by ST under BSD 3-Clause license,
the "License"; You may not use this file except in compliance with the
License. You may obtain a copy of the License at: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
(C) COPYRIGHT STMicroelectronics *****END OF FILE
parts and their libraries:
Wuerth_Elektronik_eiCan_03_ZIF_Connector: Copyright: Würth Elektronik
